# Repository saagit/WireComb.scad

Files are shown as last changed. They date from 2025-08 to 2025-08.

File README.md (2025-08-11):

# WireComb.scad
This is the OpenSCAD source for a parameterized cable wire comb that is
used to maintain the arrangement of wires within a cable harness or of
cables within a bundle.

The comb is made up of bars that when fitted together make rows of radiused
holes to run wires through.  The bars fit together using pegs facing one
way and holes to receive the pegs facing the other way.

Four different pieces can be rendered from this file:

| Peg End | Center | HoleEnd | 2RowSolid |
| --- | --- | --- | --- |
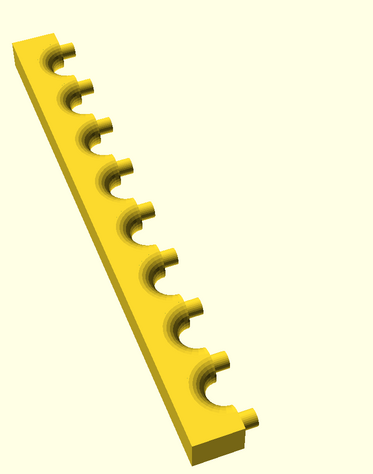
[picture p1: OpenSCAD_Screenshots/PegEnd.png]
Image of a PegEnd piece
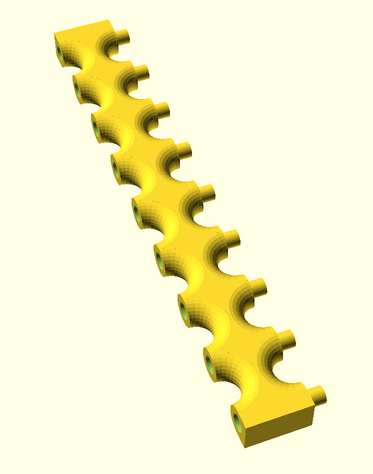
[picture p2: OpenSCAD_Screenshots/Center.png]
Image of a Center piece
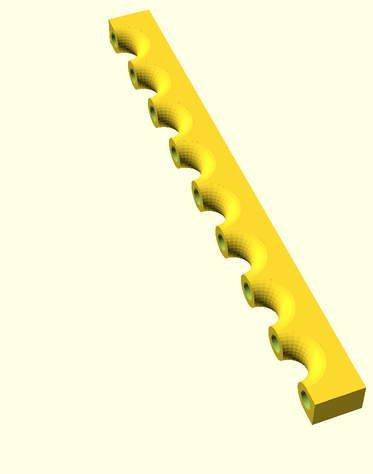
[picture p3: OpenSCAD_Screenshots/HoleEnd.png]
Image of a HoleEnd piece
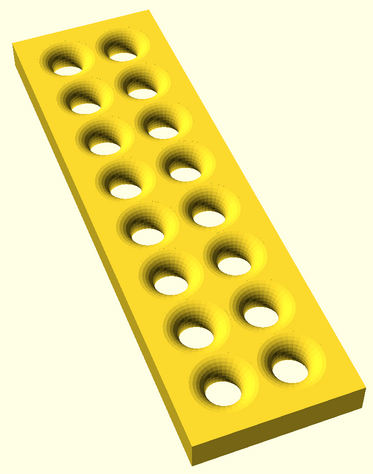
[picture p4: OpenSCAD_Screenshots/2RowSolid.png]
Image of a 2RowSolid piece
|  |  |  |  |

Depending on how many rows you want in your comb, zero or more "Center" pieces
may be fitted between a "HoleEnd" and a "PegEnd".

I rendered "2RowSolid" for illustrative purposes, but it could be printed and/or
modified if needed.

The number of holes in a row, the diameter of the holes, the thickness of
the comb and other parameters can be modified by editing the
[source](WireComb.scad) or using OpenSCAD's Customizer as seen on the right
side of this screenshot:

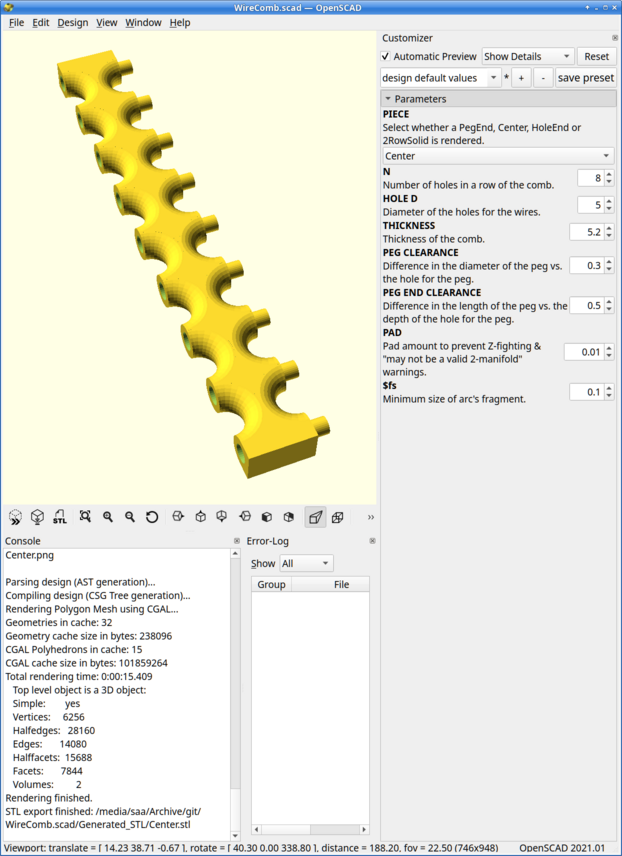
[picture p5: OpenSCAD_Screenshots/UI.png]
Image of OpenSCAD UI


I print "PegEnd" and "HoleEnd" pieces with the flat, rectangular side down.  I
print "Center" pieces with the holes down and pegs up.  On my low-end printer,
this causes ridges to be formed on the edges of the holes which I remove by
pushing the shank of an appropriately sized drill bit into the hole.  For all
pieces I print a brim on the base plate to minimize warpage and to consolidate
the first layer of a "Center" piece.

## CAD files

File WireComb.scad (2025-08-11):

// This is the OpenSCAD source for a parameterized cable wire comb that is
// used to maintain the arrangement of wires within a cable harness or of
// cables within a bundle.
//
// The comb is made up of bars that when fitted together make rows of radiused
// holes to run wires through.  The bars fit together using pegs facing one
// way and holes to receive the pegs facing the other way.  Four different
// pieces can be rendered from this file.  "PegEnd" is flat on one side and
// has pegs on the other side.  Similarly, "HoleEnd" is flat on one side and
// has holes for pegs on the other side.  The "Center" piece has pegs on
// one side and holes for pegs on the other side.  Depending on how many rows
// you want in your comb, zero or more "Center" pieces may be fitted
// between a "HoleEnd" and a "PegEnd".  Another option is to render a solid
// two row wire comb using "2RowSolid".
//
// The number of holes in a row, the diameter of the holes, the thickness of
// the comb and other parameters can be modified using OpenSCAD's Customizer
// (or by editing this file).
//
// I print "PegEnd" and "HoleEnd" pieces with the flat side opposite the pegs
// or peg holes down.  I print "Center" pieces with the holes down and pegs
// up.  For all pieces I print a brim on the base plate to minimize warpage
// and to join the first layer of a "Center" piece all together.

// BSD Zero Clause License
//
// Copyright (c) 2025 Scott A. Anderson
//
// Permission to use, copy, modify, and/or distribute this software for any
// purpose with or without fee is hereby granted.
//
// THE SOFTWARE IS PROVIDED "AS IS" AND THE AUTHOR DISCLAIMS ALL WARRANTIES
// WITH REGARD TO THIS SOFTWARE INCLUDING ALL IMPLIED WARRANTIES OF
// MERCHANTABILITY AND FITNESS. IN NO EVENT SHALL THE AUTHOR BE LIABLE FOR ANY
// SPECIAL, DIRECT, INDIRECT, OR CONSEQUENTIAL DAMAGES OR ANY DAMAGES
// WHATSOEVER RESULTING FROM LOSS OF USE, DATA OR PROFITS, WHETHER IN AN
// ACTION OF CONTRACT, NEGLIGENCE OR OTHER TORTIOUS ACTION, ARISING OUT OF OR
// IN CONNECTION WITH THE USE OR PERFORMANCE OF THIS SOFTWARE.

// Select whether a PegEnd, Center, HoleEnd or 2RowSolid is rendered.
PIECE = "PegEnd"; // [PegEnd, Center, HoleEnd, 2RowSolid]

// Number of holes in a row of the comb.
N = 8;
// Diameter of the holes for the wires.
HOLE_D = 5;
// Thickness of the comb.
THICKNESS = 5.2;  // 0.4
// Difference in the diameter of the peg vs. the hole for the peg.
PEG_CLEARANCE = 0.3;  // 0.1
// Difference in the length of the peg vs. the depth of the hole for the peg.
PEG_END_CLEARANCE = 0.5;  // 0.1
// Pad amount to prevent Z-fighting & "may not be a valid 2-manifold" warnings.
PAD = 0.01;  // 0.01
// Minimum size of arc's fragment.
$fs = 0.1;  // 0.1

/* [Hidden] */
// The radius of the holes for the wires.
HOLE_R = HOLE_D / 2;
// The radiused holes for the wires are formed as tori.  The body of the torus
// has the same diameter as the thickness of the comb.
TORUS_D = THICKNESS;
TORUS_R = TORUS_D / 2;
// Center to center distance between the radiused wire holes.
HOLE_C_TO_C = HOLE_D + TORUS_D;
// Total depth of the wire comb form.
DEPTH = N * (HOLE_D + TORUS_D) + TORUS_D;
// PAD * 2 is used frequently.
PADX2 = PAD * 2;

// Create a torus centered on the origin with a center hole of radius
// <hole_radius> and the body of the torus having a radius of <torus_radius>.
module torus(torus_radius, hole_radius)
{
    rotate_extrude()
        translate([hole_radius + torus_radius, 0, 0])
            circle(r=torus_radius);
}

// Create a shape that is described by the central hole of a torus centered on
// the origin with whose radius is <hole_radius> and the body of the torus
// having a radius of <torus_radius>.
module torus_hole(torus_radius, hole_radius)
{
    cylinder_height = (torus_radius + PAD) * 2;
    cylinder_radius = torus_radius + hole_radius;
    difference() {
        cylinder(h=cylinder_height, r=cylinder_radius, center=true);
        torus(torus_radius, hole_radius);
    }
}

// Create an array of <n_x> by <n_y> tori holes with the first centered on the
// origin and the others extending out along the positive X and Y axes
// separated by <center_to_center>.
module torus_hole_array(torus_radius, hole_radius, center_to_center, n_x, n_y)
{
    for (x = [0 : center_to_center : center_to_center * (n_x - 1)])
        for (y = [0 : center_to_center : center_to_center * (n_y - 1)])
            translate([x, y, 0])
                torus_hole(torus_radius, hole_radius);
}

// Create a row of <n_y> cylinders with the first having its axis on the X
// axis and its base on the YZ plane and the others extending out along the Y
// axis separated by <center_to_center>.
module row_of_cylinders(cylinder_height, cylinder_diameter,
                        center_to_center, n_y)
{
    for (y = [0 : center_to_center : center_to_center * n_y])
        translate([0, y, 0])
            rotate([0, 90, 0])
                cylinder(h=cylinder_height, d=cylinder_diameter);
}

// Subsequent modules make use of globals instead of parameters.

// Create N cylinders positioned to be row <row_n> of either pegs or peg holes.
module row_of_pegs_or_holes(row_n, cylinder_height, cylinder_diameter)
{
    x_pos = (TORUS_D + HOLE_R) + ((row_n - 1) * HOLE_C_TO_C) - PAD;
    translate([x_pos, TORUS_R, TORUS_R])
        row_of_cylinders(cylinder_height=cylinder_height + PAD,
                         cylinder_diameter=cylinder_diameter,
                         center_to_center=HOLE_C_TO_C, n_y=N);
}

// Create the pegs for row <row_n>.
module row_of_pegs(row_n)
{
    row_of_pegs_or_holes(row_n,
                         cylinder_height=TORUS_R, cylinder_diameter=TORUS_R);
}

// Create the peg holes for row <row_n>.
module row_of_peg_holes(row_n)
{
    row_of_pegs_or_holes(row_n,
                         cylinder_height=TORUS_R + PEG_END_CLEARANCE,
                         cylinder_diameter=TORUS_R + PEG_CLEARANCE);
}

// Create the shape of an entire wire comb that has two holes along the X axis
// and <N> holes along the Y axis.  It will extend out from the origin in the
// positive X, Y and Z axes.
module comb_form()
{
    difference() {
        cube([2 * (HOLE_D + TORUS_D) + TORUS_D, DEPTH, THICKNESS]);
        translate([TORUS_D + HOLE_R, TORUS_D + HOLE_R, TORUS_R])
            torus_hole_array(TORUS_R + PAD, HOLE_R, HOLE_C_TO_C, 2, N);
    }
}

// Create a cube to intersect with comb_form() to create PIECE but without
// pegs and holes for pegs.
module piece_clip_box()
{
    if (PIECE == "PegEnd") {
        translate([-PAD, -PAD, -PAD])
            cube([TORUS_D + HOLE_R + PAD, DEPTH + PADX2, THICKNESS + PADX2]);
    } else if (PIECE == "Center") {
        translate([TORUS_D + HOLE_R, -PAD, -PAD])
            cube([TORUS_D + HOLE_D, DEPTH + PADX2, THICKNESS + PADX2]);
    } else if (PIECE == "HoleEnd") {
        translate([2 * TORUS_D + 3 * HOLE_R, -PAD, -PAD])
            cube([TORUS_D + HOLE_R + PAD, DEPTH + PADX2, THICKNESS + PADX2]);
    }
}

// Create PIECE but without pegs and holes for pegs.
module piece_without_pegs_nor_peg_holes()
{
    intersection() {
        comb_form();
        piece_clip_box();
    }
}

if (PIECE == "PegEnd") {
    piece_without_pegs_nor_peg_holes();
    row_of_pegs(1);
} else if (PIECE == "Center") {
    difference() {
        piece_without_pegs_nor_peg_holes();
        row_of_peg_holes(1);
    }
    row_of_pegs(2);
} else if (PIECE == "HoleEnd") {
    difference() {
        piece_without_pegs_nor_peg_holes();
        row_of_peg_holes(2);
    }
} else if (PIECE == "2RowSolid") {
    comb_form();
}
